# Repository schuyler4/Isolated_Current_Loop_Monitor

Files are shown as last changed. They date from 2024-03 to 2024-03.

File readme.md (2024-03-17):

<h1> Isolated Current Loop Monitor </h1>

<center>

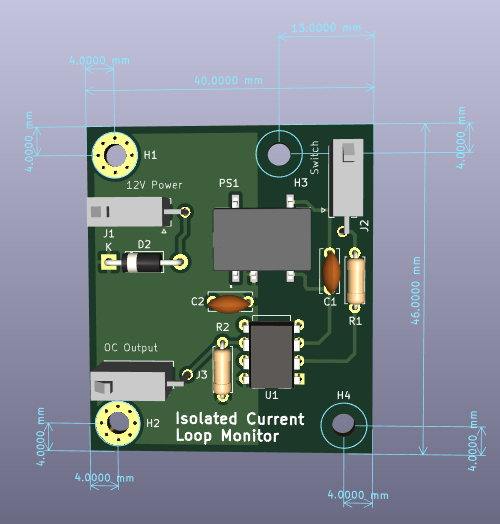
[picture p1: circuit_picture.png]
Circuit Picture

</center>

<p> This circuit monitors the state of a switch (or many switches in series) with an isolated signal. This is the only way to truly monitor the state of a switch without any
information about the signal that the switch is switching. 
</p>
<h3>Inputs</h3>
<ul>
<li>12V Power</li>
<li>Switch Loop (Connect each end to switch connector)</li>
</ul>
<h3>Output</h3>
The output is open collector with a 10k pull up resistor. When the 
switch loop is closed, the open collector pulls low, and when the switch
is open, it releases.

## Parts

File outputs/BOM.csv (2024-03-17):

Reference | Value | Qty | Part # | Digikey Part # | Unit Price
C1 | 10uF | 1 | FG20X7R1H106KRT06 | 445-173297-1-ND | 1.29
C2 | 2.2uF | 1 | RDER71H225K2M1H03A | 490-9164-1-ND | 0.74
D2 | 1N5817 | 1 | 1N5817 | 497-4547-1-ND | 0.42
J1 | 12V Power | 1 | 2125280200 | 900-2125280200-ND | 2.13
J2 | Current Loop Input | 1 | 2125280200 | 900-2125280200-ND | 2.13
J3 | Open Collector Output | 1 | 2125280200 | 900-2125280200-ND | 2.13
PS1 | PDSE1-S12-S5-M | 1 | PDSE1-S12-S5-M | 102-PDSE1-S12-S5-M-ND | 3.45
R1 | 1k | 1 | CFF14JT1K00 | 738-CFF14JT1K00CT-ND | 0.12
R2 | 10k | 1 | CF14JT10K0 | CF14JT10K0CT-ND | 0.1
U1 | 6N139 | 1 | 6N139-ND | 6N139-ND | 1.79
total: |  |  |  |  | 14.3

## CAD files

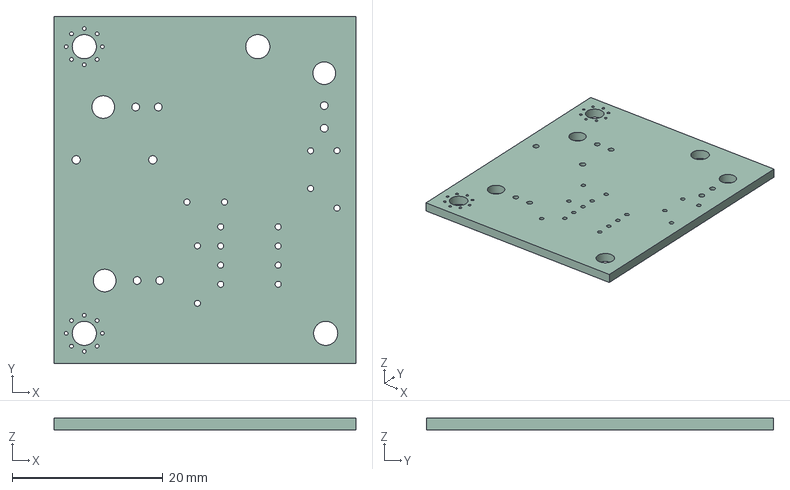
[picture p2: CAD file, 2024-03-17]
outputs/Isolated_Current_Loop_Monitor.step
40.0 x 46.0 x 1.60 mm

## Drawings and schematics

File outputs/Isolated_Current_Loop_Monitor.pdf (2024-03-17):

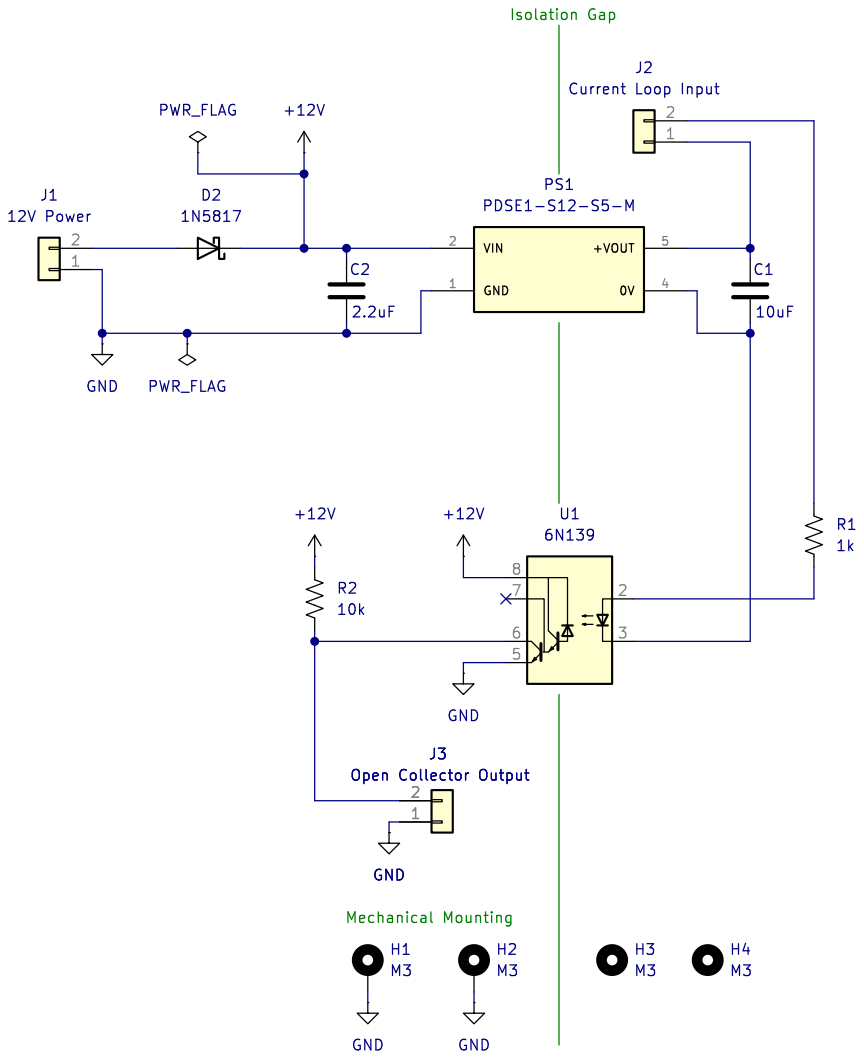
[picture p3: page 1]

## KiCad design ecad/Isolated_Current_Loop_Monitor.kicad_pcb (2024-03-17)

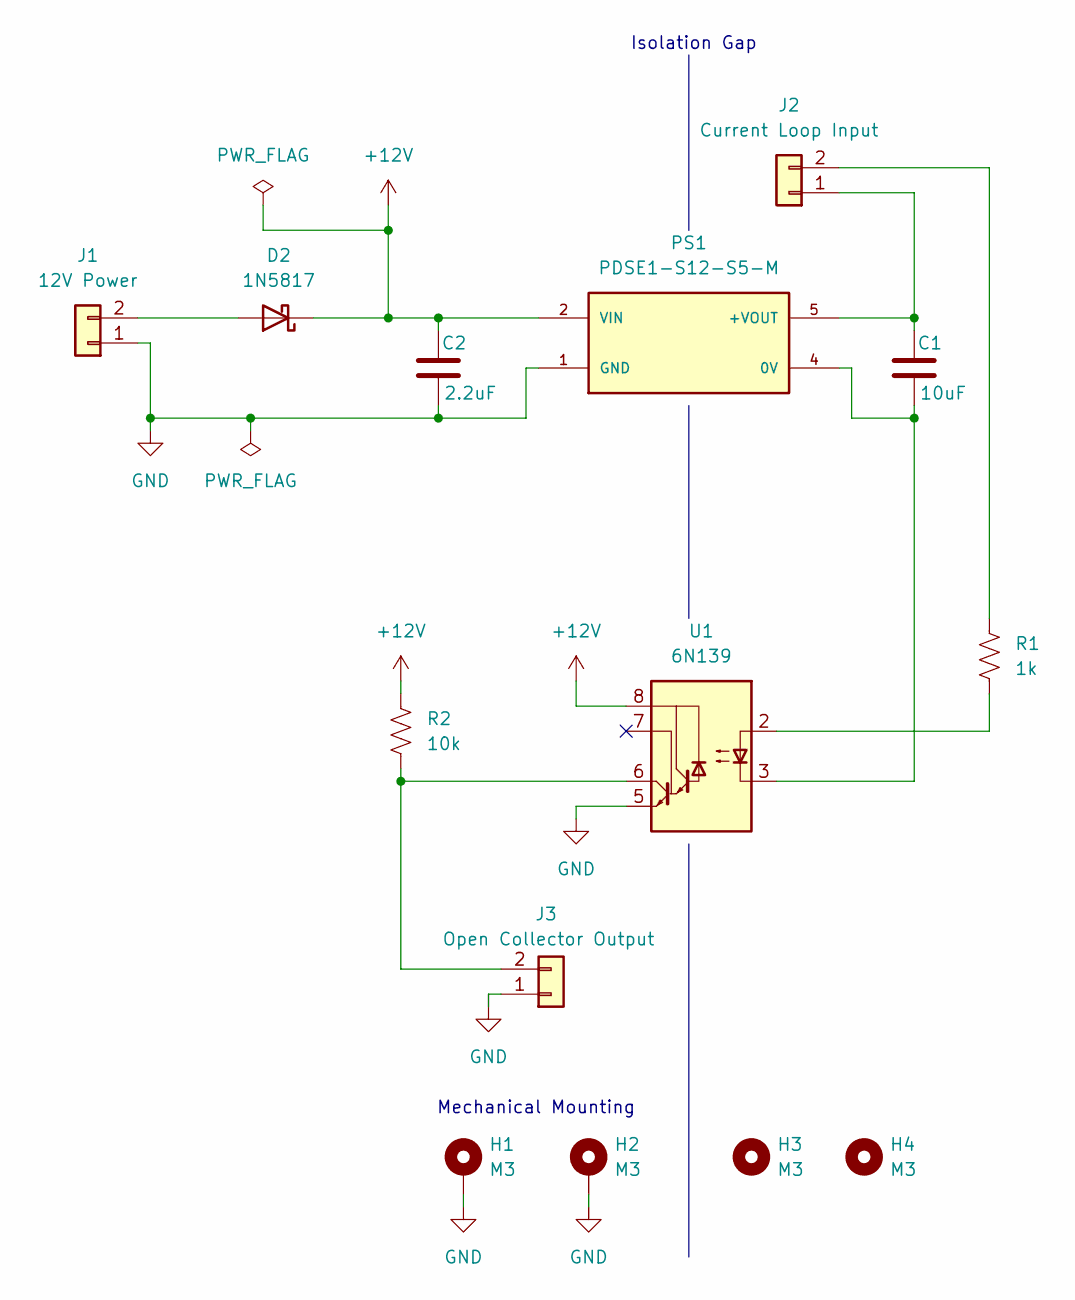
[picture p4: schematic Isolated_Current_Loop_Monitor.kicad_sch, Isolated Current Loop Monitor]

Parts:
C1: 10uF; C_Disc_D6.0mm_W2.5mm_P5.00mm; Part # FG20X7R1H106KRT06; Digikey Part # 445-173297-1-ND
C2: 2.2uF; C_Disc_D6.0mm_W2.5mm_P5.00mm; Part # RDER71H225K2M1H03A; Digikey Part # 490-9164-1-ND
D2: 1N5817; D_DO-41_SOD81_P10.16mm_Horizontal; Part # 1N5817; Digikey Part # 497-4547-1-ND
H1, H2: M3; MountingHole_3.2mm_M3_Pad_Via
H3, H4: M3; MountingHole_3.2mm_M3
J1: 12V Power; MOLEX_2125280200; Part # 2125280200; Digikey Part # 900-2125280200-ND
J2: Current Loop Input; MOLEX_2125280200; Part # 2125280200; Digikey Part # 900-2125280200-ND
J3: Open Collector Output; MOLEX_2125280200; Part # 2125280200; Digikey Part # 900-2125280200-ND
PS1: PDSE1-S12-S5-M; CONV_PDSE1-S12-S5-M; PARTREV 1.0; Digikey Part # 102-PDSE1-S12-S5-M-ND
R1: 1k; R_Axial_DIN0207_L6.3mm_D2.5mm_P7.62mm_Horizontal; Part # CFF14JT1K00; Digikey Part # 738-CFF14JT1K00CT-ND
R2: 10k; R_Axial_DIN0207_L6.3mm_D2.5mm_P7.62mm_Horizontal; Part # CF14JT10K0; Digikey Part # CF14JT10K0CT-ND
U1: 6N139; DIP-8_W7.62mm; Part # 6N139-ND; Digikey Part # 6N139-ND

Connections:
+12V: C2.1, D2.1 (K), PS1.2 (VIN), R2.1, U1.8 (VCC)
GND: C2.2, H1.1, H2.1, J1.1, J3.1, PS1.1 (GND), U1.5 (GND)
unnamed: D2.2 (A), J1.2
unnamed: C1.1, J2.1, PS1.5 (+VOUT)
unnamed: J2.2, R1.1
unnamed: J3.2, R2.2, U1.6 (VO2)
unnamed: C1.2, PS1.4 (0V), U1.3 (C2)
unnamed: R1.2, U1.2 (C1)

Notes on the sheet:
Isolation Gap
Mechanical Mounting

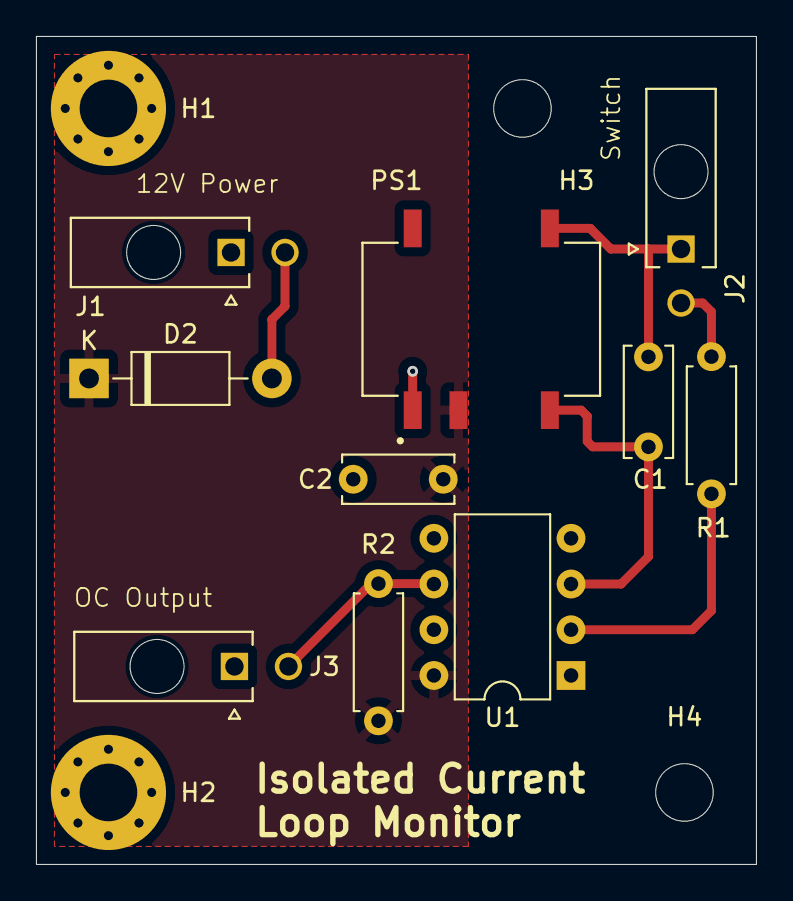
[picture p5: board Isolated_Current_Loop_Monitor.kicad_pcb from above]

Board: 2 copper layers, 40.0 x 46.0 mm, 14 parts (0 on the bottom side), 8 nets.
